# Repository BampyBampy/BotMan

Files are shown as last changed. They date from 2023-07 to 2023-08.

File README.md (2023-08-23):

# BotMan
A small animatronic desktop robot based on [YouTube Video](https://www.youtube.com/watch?v=FmKTiH5Lca4) found on the 稚晖君 channel (see image below).

To see my progress read my [diary here](Diary.md)

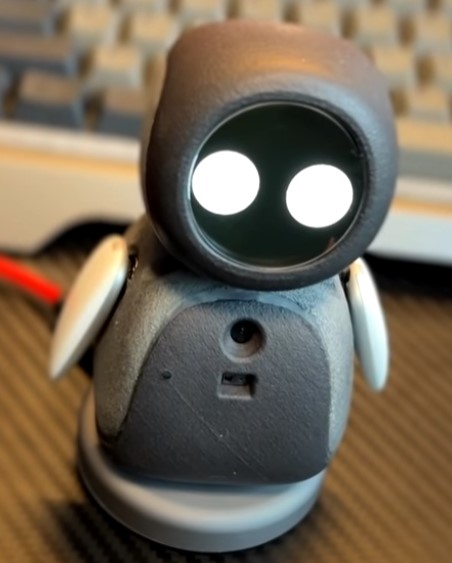
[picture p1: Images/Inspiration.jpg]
The inspiration for this project


## Update!!
Due to a mix up with servo sizes (see blog for more information on my mistake), I will be going for a bigger bot along the lines of the $800 Moxie. It will make the engineering easier and will make it possible to squeeze more things in.

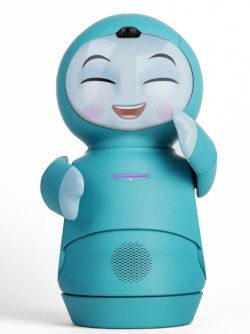
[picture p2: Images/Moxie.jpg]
The inspiration (V2) for this project


Although the channel provides some CAD drawings and a quick build video in Mandarin, it is incomplete or some elements may have been lost during the automated translations. So I will be designing and building my version from scratch (using their design as a template). There are other reasons for doing this including;

1. The main reason is this is a learning experience for me. I have never designed a robot before, I have never used CAD and I have limited experience with Arduino and 3D printing.
2. The components I have available to me will be different to theirs, so most of the dimensions and design would need tweaking anyway.
3. I don't have the facilities to produce my own circuit boards, so my design will need to be based on Arduino (or similar)
4. I intend to swap the static base for a wheeled base to allow my bot to move around the desk. This will need incorporating into the main design.

## The Design Build Order
1. **The arms** - I have chosen to develop these first because they are the most complex part of the physical design. They need 2 DOF in the same shoulder joint. (See The Specs below)
2. **The body** - This cant be designed until I have completed arm mechanisms to house. The interface to the head and base will need to be incorporated into the design of the body.
3. **The head**
4. **The base**
5. **The software** - As a VBA and Python developer, this part worries me the least and will be developed last.

## The Specs (Outline)
1. **The arms**
   - 2 Degrees of movement (1) Rotating from pointing down to pointing straight up. (2) Flapping in and out
   - Act as an input device. i.e. Physically moving the right arm up could increase the sound volume
   - Will not be able to pick anything up. Arms are animatronic only
3. **The body**
   - Will house the arm mechanisms
   - Will house the servo that will turn the body left and right relative to the stand
   - May house the voice recognition microphone
   - May house touch sensors on the belly and back to act as inputs
   - May have LEDs to make the belly glow
5. **The head**
   - Will have 2 degrees of movement (1) Up and down, i.e. nodding (2) Left and right, i.e. head shaking
   - Will house the display screen
   - May house the voice recognition microphone
   - May house touch sensors on the top to act as inputs
7. **The base**
   - Temporary static base while the software is developed
   - May contain a speaker, LED indicators, and various ports to connect to the outside world
9. **The software**
   - All joints to have smooth servo controls (remove jerkiness)
   - Voice recognition
   - Voice synthesis 
   - Interface with other computers in the room over wifi so it can send and receive instructions
   - Needs a low-battery detector
11. **Alternative bases**
    - Investigate different wheeled designs
    - Needs to be able to stop before falling off the edge of the desk

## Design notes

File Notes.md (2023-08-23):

# Notes
This is just a raw dumping ground for bits and pieces I found useful. There is zero logic to the layout of this page
## Calculate the distance between 2 cogs
In this example, we have two cogs, one with 16 teeth and one with 14 teeth with a module of 1.38. The formula is

Distance = (Module x (Teeth 1 + Teeth 2)) / 2
=(1.38 x (16 + 14)) / 2
= 20.7mm

Shoulder cogs will be 15mm horizontally apart and 14.26mm vertically apart

See [https://www.youtube.com/watch?v=IhcLSx2ppUY](https://www.youtube.com/watch?v=IhcLSx2ppUY)

## How to space shafts a set distance apart
See [https://forum.freecad.org/viewtopic.php?t=53574](https://forum.freecad.org/viewtopic.php?t=53574)

## Adjusted Dimensions for 3D Printing
This is just a bunch of notes to hold the results of 3d printing experiments and mess-ups.

**New Experiment** - Dont use supports when printing holes under 4mm in dia

**Standard meshing to use for all prints** - Based on an exported standard mesh with 0.1mm surface deviation, 10-degree angular deviation, and relative surface deviation

**10mm Bearing** - Holes for 10mm bearing = 5.2mm(r) = 10mm dia hole when printed. Dia of bearing inner = 5.8mm dia = 5.9mm dia when printed (try 5.9 next to give slightly bigger)

**15mm Bearing** - Holes for 15mm bearing = 7.65mm(r) = 15 mm dia hole when printed. Dia of bearing inner = 4.95mm(r) = 9.9mm dia when printed

**Servo Cog** - Holes to accept servo cogs (2.4r) = 4.8 dia hole when printed. Is a tight fit which is needed. Holes for servo self-tapping screws 1.4 Dia

**M2 Screws** Holes to pass through, print = 1mm(r), drill = 2mm dia. Holes to tap, print 0.7mm(r), drill 1.2mm dia.

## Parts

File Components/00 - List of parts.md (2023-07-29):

# List of Components
This list details all of the components used in the making of the bot. Note this list is in constant development and as a result is incomplete, so quantities and specs may change over time.
## Servos and/or Motors
1. **SG90 Servo (x2)**
   - For a FreeCAD 3d model see the "Component - SG90 Servo.FCStd" file
   - Note SG90 dimensions can vary by a few millimeters from make to make, so please check your dimensions before using this model
## Standard Components
1. **Bearing - 6mm x 10mm x 3mm (x2)**
   - For a FreeCAD 3d model see the "Component - 6mm x 10mm x 3mm.FCStd" file
## 3D Printed Parts
### Arm Assembly
1. **Shoulder Servo Rotational Cog 16 teeth v2 (x2)**
   - See the FreeCad 3d model "Shoulder Servo Rotational Cog 16 teeth v2.FCStd"
   - This cog attaches to the servo that rotates the arm between downward and upward positions.
   - 16 Teeth with a module of 1.38.
   - Will be matched with a cog attached to the arm
2. **Shoulder Cog and Inner Pivot (x2)**
   - See the FreeCad 3d model "Shoulder Cog and Inner Pivot.FCStd"
   - This cog is on the inside of the arm mechanism and provides a part of the pivot the arm rotates on.
   - Pairs with *Outer Shoulder and Pivot*
3. **Shoulder Pivot Outer (x2)**
   - See the FreeCad 3d model "Shoulder Pivot Outer.FCStd"
   - This is the outer pivot element of the shoulder pivot
   - Pairs with *Shoulder Gear and Pivot*
4. **Flapper Lever (x2)**
   - See the FreeCad 3d model "Flapper lever.FCStd"   
   - Converts rotational servo movement into a push / pull motion via the flapper bar and stoppers
5. **Flapper Bar (x2)**
   - See the FreeCad 3d model "flapper Bar.FCStd"
   - Transfers the movement from the servo to the flapping pivot point in the shoulder
6. **Flapper Bar Stopper (x4)**
   - See the FreeCad 3d model "Flapper Bar Stopper.FCStd"
   - Screws onto the flapper bar so the flapper lever can push on the flapper bar
##Test rigs
1. **Arm Test Rig (x1)**
   - See the FreeCad 3d model "Arm Test Rig - NOT A PART OF THE FINAL ASSEMBLY.FCStd"
   - A simple test rig to hold all the shoulder components in place for testing

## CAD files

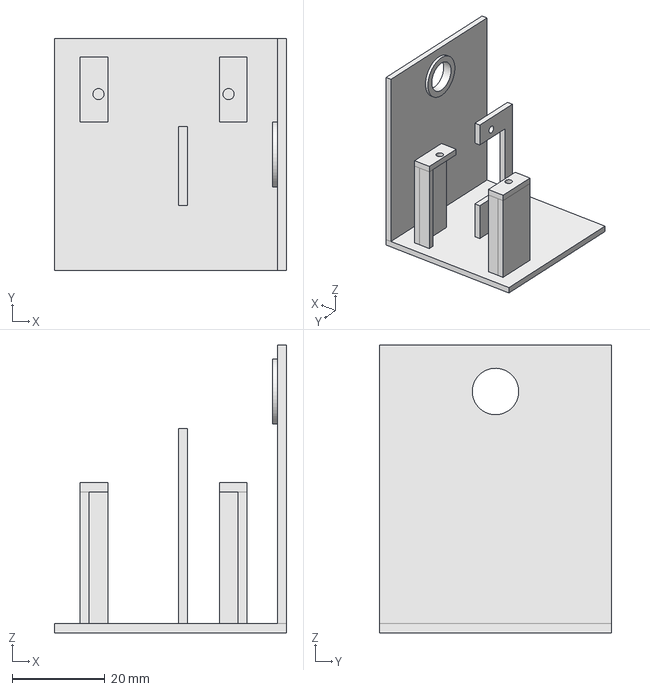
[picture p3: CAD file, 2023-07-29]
Components/Arm Test Rig - NOT A PART OF THE FINAL ASSEMBLY.FCStd
50.0 x 50.0 x 62.0 mm

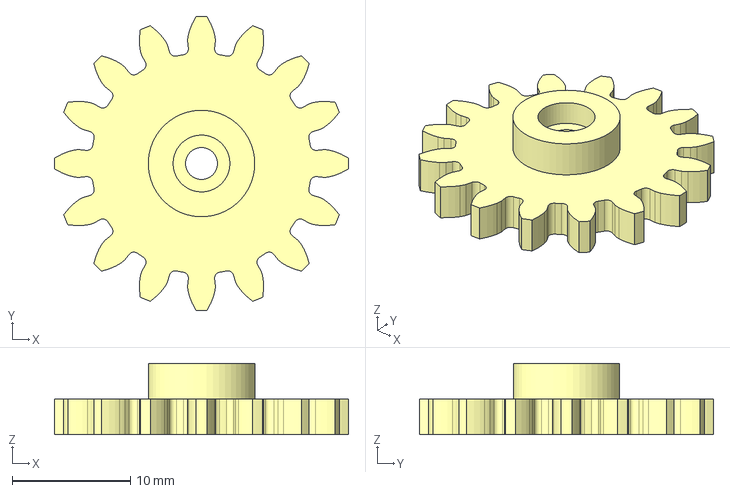
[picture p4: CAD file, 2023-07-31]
Components/Shoulder Servo Rotational Cog 16 teeth v3.FCStd
24.8 x 24.8 x 6.00 mm

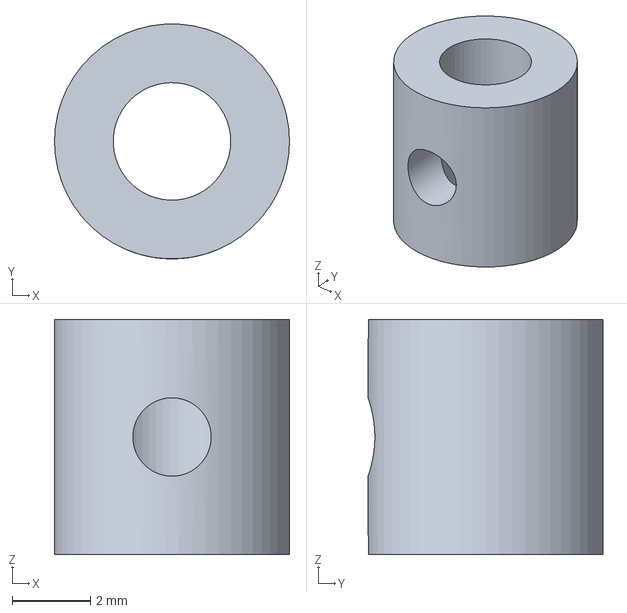
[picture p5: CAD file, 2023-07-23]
Components/Flapper Bar Stopper.FCStd
6.00 x 5.99 x 6.00 mm

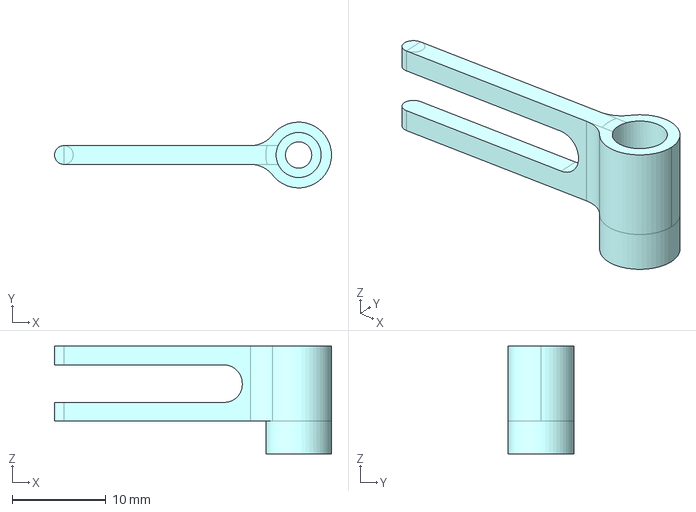
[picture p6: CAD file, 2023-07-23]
Components/flapper lever.FCStd
29.5 x 7.00 x 11.5 mm

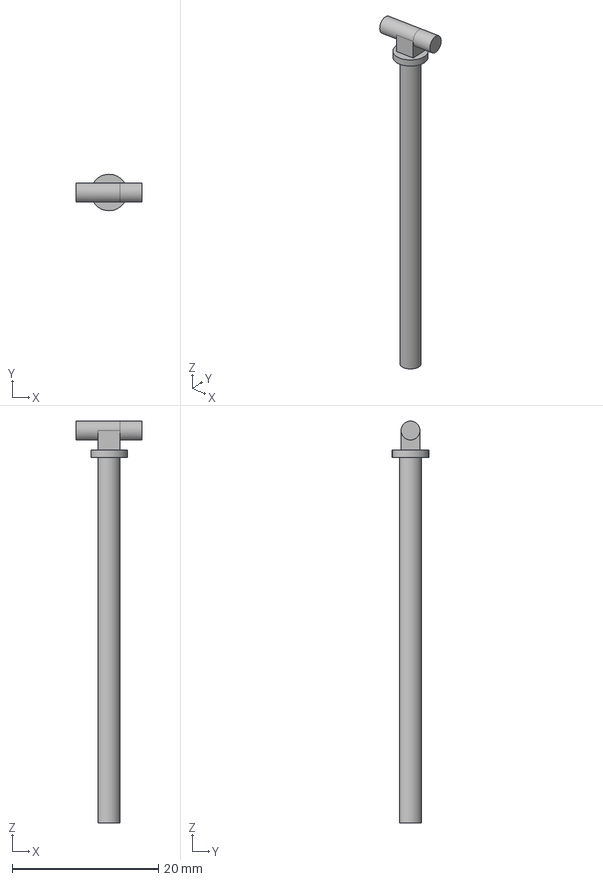
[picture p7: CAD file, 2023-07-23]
Components/Flapper Bar.FCStd
9.00 x 5.00 x 55.0 mm

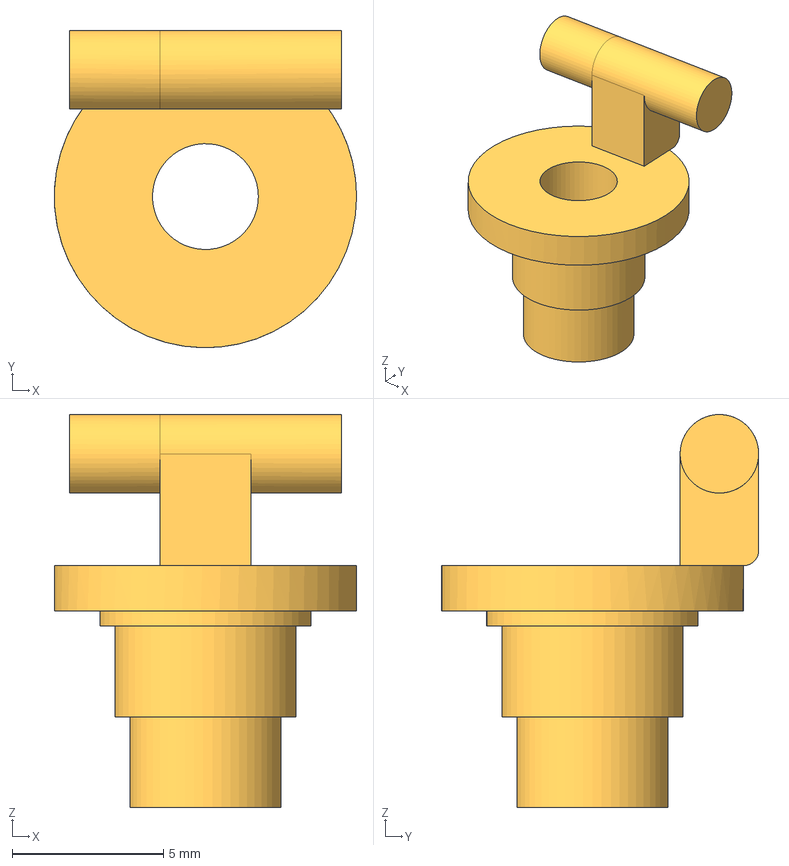
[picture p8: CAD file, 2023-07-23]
Components/Shoulder Pivot Outer.FCStd
10.00 x 10.5 x 13.0 mm

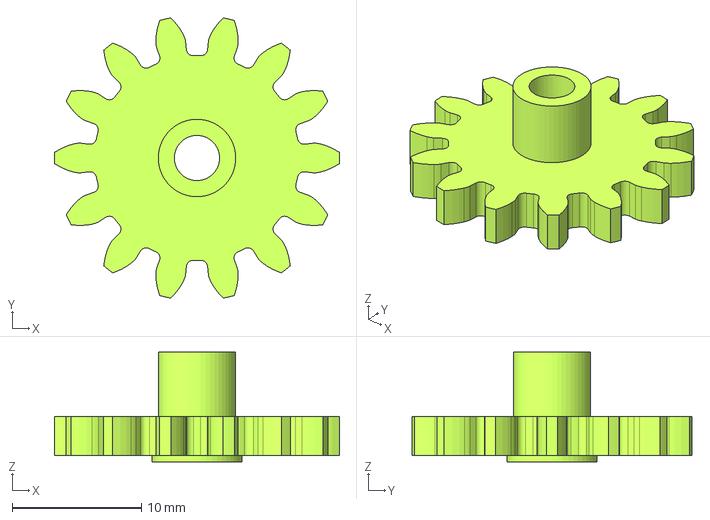
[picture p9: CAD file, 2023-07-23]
Components/Shoulder Cog and Inner Pivot.FCStd
22.1 x 21.7 x 8.50 mm

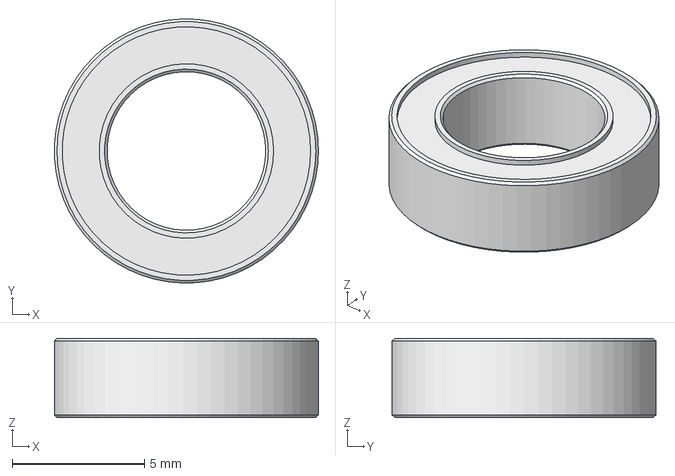
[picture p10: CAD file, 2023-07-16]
Components/Component - 6mm x 10mm x 3mm Bearing.FCStd
9.99 x 10.00 x 3.00 mm

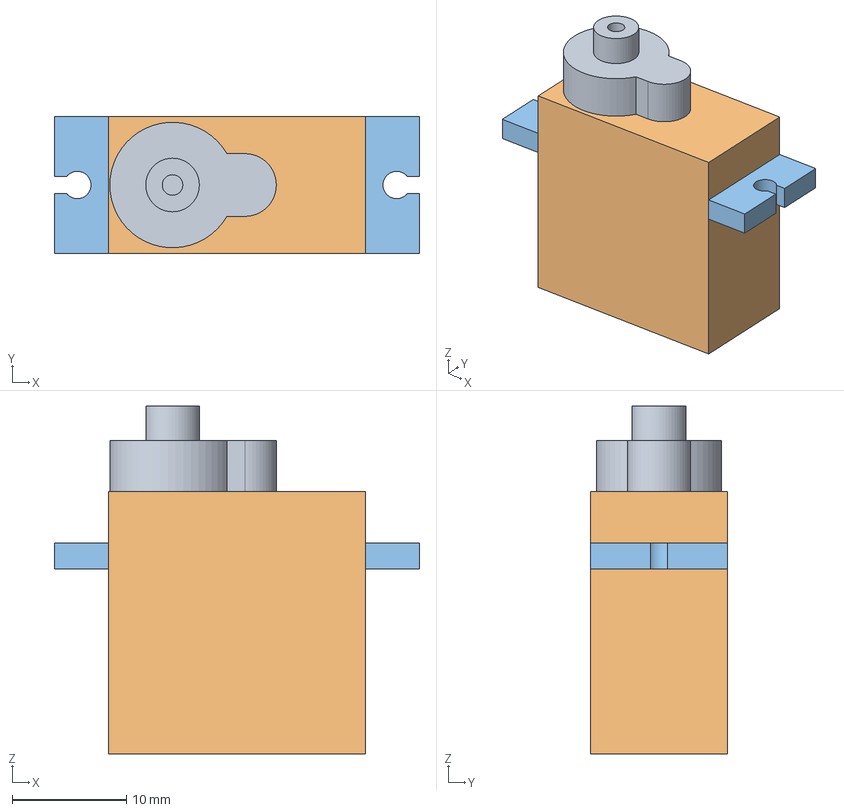
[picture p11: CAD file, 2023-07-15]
Components/Component - SG90 Servo.FCStd
32.0 x 12.0 x 30.5 mm
SG90 Body
Main Body
Mounting Shoulder

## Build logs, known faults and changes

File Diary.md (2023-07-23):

# Diary of a Gen-X robot builder
This is only provided to give you some clues to the decisions made during the development of the project. i.e. so you can learn from my mistakes.
### 23rd July 2023
In the middle of the night, I realised my first design for the arm assembly was massively flawed. If the arm rotated so it was pointing up or down, the lever to push/pull the flapping mechanism would disengage. So that was redesigned today and now looks more like the mechanism in the original bot I'm using as a template for this project.

I also realised that having the drive cogs offset vertically and horizontally was unnecessary and would result in lots of unnecessary maths. So in this version, one cog is directly above the other with no horizontal offset. This should make mounting the servos much easier.

The next stage is to design some arms and to 3d print everything so I can test everything works. For the time being the arms will be a simple bar - I won't design the cosmetic elements until the very end of the project.

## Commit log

2023-07-15 Add files via upload
    FreeCAD model of an SG90 servo - Note dimensions on SG90 servos vary, so yours may be different to this model
    [Component - SG90 Servo.FCStd]
2023-07-15 Add files via upload
    FreeCAD 3D model of SG90 servo. Note - Although SG90 servos are fairly standard there are variations to be found where dimensions will differ by 1 or 2 mm. Please check the dimensions before using in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
    [Component - SG90 Servo.FCStd]
2023-07-15 Create List of components.md
    List of bought in and printed components used in the bot
2023-07-15 Add files via upload
    Cog that attaches to the servo that rotates the arms between downward and upward positions.
    [3DP - Shoulder Servo Cog.FCStd]
2023-07-15 Add files via upload
    Outer shoulder joint and pivot mechanism
    [3DP - Outer Shoulder and Pivot.FCStd]
2023-07-15 Add files via upload
    Shoulder gear and pivot mechanism
    [3DP - Shoulder Gear and Pivot.FCStd]
2023-07-16 Add files via upload
    3D Model of a 6mm x 10mm x 3mm bearing
    [Component - 6mm x 10mm x 3mm Bearing.FCStd]
2023-07-16 Create Notes
    Created a dumping ground for handy notes
2023-07-16 Create Notes.md
    A dumping ground for handy notes
2023-07-16 Add files via upload
    Sub-assembly of arm joint
    [Arm Sub Assembly.FCStd]
2023-07-23 Add files via upload
    Redesigned cog to drive the rotation of the shoulder joint
    [Shoulder Servo Rotational Cog 16 teeth v2.FCStd]
2023-07-23 Add files via upload
    Cog that receives the drive to rotate the shoulder. Also acts as a pivot for the shoulder
    [Shoulder Cog and Inner Pivot.FCStd]
2023-07-23 Add files via upload
    The outer part of the shoulder pivot. Also provides the pivot point for the shoulders flapping movement
    [Shoulder Pivot Outer.FCStd]
2023-07-23 Add files via upload
    This bar transfers pushing and pulling movement to the shoulder joint
    [Flapper Bar.FCStd]
2023-07-23 Add files via upload
    This lever takes rotational movement from a servo and applies it as pushing/pulling motion on the flapper bar
    [flapper lever.FCStd]
2023-07-23 Add files via upload
    These are screwed onto the flapper bar and transfer movement from the flapper lever to the flapper bar
    [Flapper Bar Stopper.FCStd]
2023-07-23 Add files via upload
    V1 of the assembly showed up several errors. For example, if the arm was in a rotated position the flapper bar lever would disengage - so I have opted for a different mechanism similar to the mechanism in the robot this is all based on.
    I have also rearranged the cogs so they are directly above one another rather than at an angle. This should make future calculations easier.
    [Arm sub-assembly v2.FCStd]
2023-07-23 Add files via upload
    Outer shoulder which forms a part of the rotational pivoting and the flapping pivoting
    [Shoulder Pivot Outer.FCStd]
2023-07-23 Add files via upload
    Provides flapping push/pull force to the arm
    [Flapper Bar.FCStd]
2023-07-23 Add files via upload
    Converts rotational servo motion into push/pull motion for the flapper bar
    [flapper lever.FCStd]
2023-07-23 Add files via upload
    Screws on to the flapper bar for the flapper lever to act on
    [Flapper Bar Stopper.FCStd]
2023-07-29 A test rig to hold components for testing
    This is a quick (and rough) jig for holding all of the arm components together so the design can be tested. This is not a part of the final assembly.
    [Arm Test Rig - NOT A PART OF THE FINAL ASSEMBLY.FCStd]
2023-07-31 Add files via upload
    Removed outside shoulder to make it easier to print
    [Shoulder Servo Rotational Cog 16 teeth v3.FCStd]
2023-08-09 Update Notes.md
    Added some hole sizes
2023-08-13 Update Notes.md
    Corrected bearing hole dimensions
